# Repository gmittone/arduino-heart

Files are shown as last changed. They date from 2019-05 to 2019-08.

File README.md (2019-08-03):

# Arduino Heart

This project is born as gift to Giovanni and Beatrice marriage.

The aesthetical design is built around an heart with in front a color display with touch, two capacitive sensors on Giovanni and Beatrice names and the marriage date. On the back can be found an Arduino Due board as main controller, an esp8266 as wifi client (via SPI), an SD card, an RTC chip and a buzzer. All hardware information, with schematics and rendering, can be found on the `hardware` folder. Main source code can be found on `src` and `include`; `lib` contains all external libraries fetched with `git submodule`; `external` contains the esp8266 firmware used as wifi client over SPI.

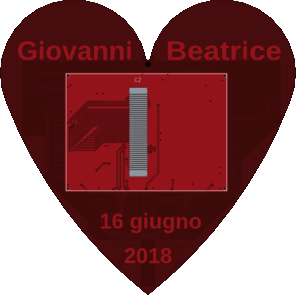
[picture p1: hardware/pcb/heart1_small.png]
Image of Yaktocat


# Features

- wifi client with WPA2 support
- rtc timer with alarm and clock
- ntp time syncronization
- sd card with FAT/FAT32
- color display and touch screen
- capacitive sensors
- jpeg/raw image rendering

# Build

Clone the main repository with the following command

```bash
git clone --recurse-submodules -j8  [repository]
```

then you can use _platformIO_, through emacs/terminal o Visual Studio Code, to build and upload the code to the arduino board through the usb programm port. Probably can be easy to write a cmake configuration file and avoid platformIO seen that the only external requirement is the Arduino framework for the _atmelsam_ platform.

Main configuration parameters live at `include/config.h` where you can find many _define_ to enable debugging to serial console and enable/disable functions.

# Todo

- use interrupt or timer to manage changes on display, like slideshow photo change or "marriage from" clean
- multiple udp/tcp socket like, ntp and webserver at the same time
- sleep mode with wake up
- memory usage optimization
- probably a clean up/unification on class management

# Thanks to

- Arduino/ESP8266 projects and all examples found on Internet
- Jiri Bilek for [WiFiSpi](https://github.com/JiriBilek/WiFiSpi) and [WiFiSpiESP](https://github.com/JiriBilek/WiFiSpiESP)
- Henning Karlsen for [UTFT](http://rinkydinkelectronics.com/library.php?id=51), [URTouch](http://rinkydinkelectronics.com/library.php?id=92) and [DS1307](http://rinkydinkelectronics.com/library.php?id=34)
- SAM scheduler [repository](https://github.com/arduino-libraries/Scheduler)
- Arduino SD library [site](http://www.arduino.cc/en/Reference/SD)
- Paul Stoffregen for [TimeAlarms](https://github.com/PaulStoffregen/TimeAlarms)
- Jack Christensen for [Timezone](https://github.com/JChristensen/Timezone)
- Bodmer for [JPEGDecoder](https://github.com/Bodmer/JPEGDecoder)
- Graham Lawrence for the [UTFT_SdRaw](https://github.com/ghlawrence2000/UTFT_SdRaw) code

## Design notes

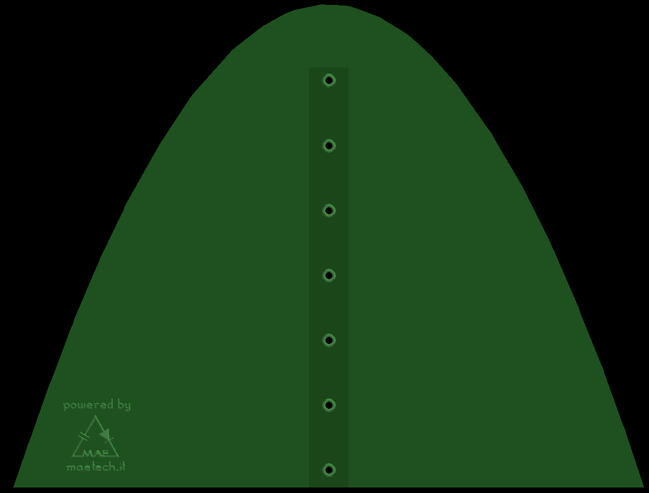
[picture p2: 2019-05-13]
hardware/pcb/stand2_2.png

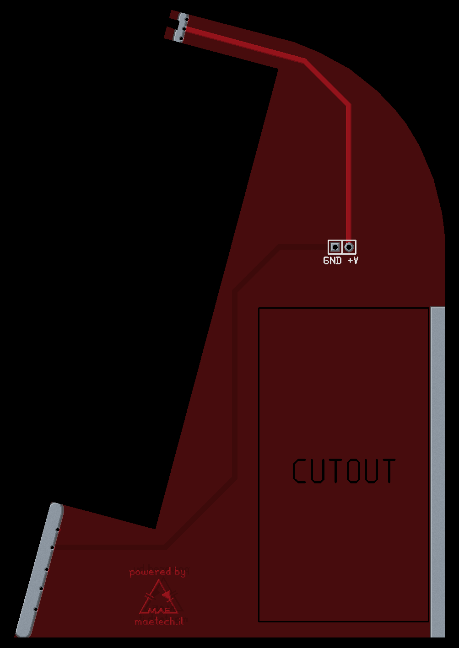
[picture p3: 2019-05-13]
hardware/pcb/stand1.png

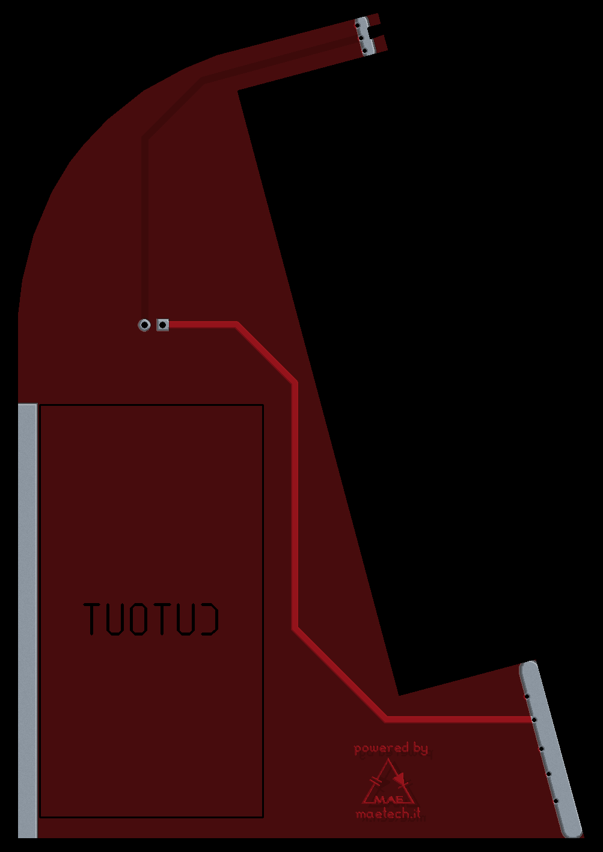
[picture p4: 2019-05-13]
hardware/pcb/stand2.png

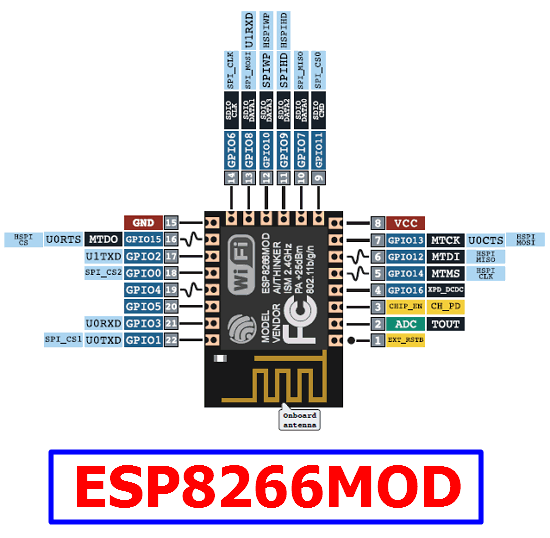
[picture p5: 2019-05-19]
hardware/pinout/ESP8266MOD-datasheet-pinout.gif

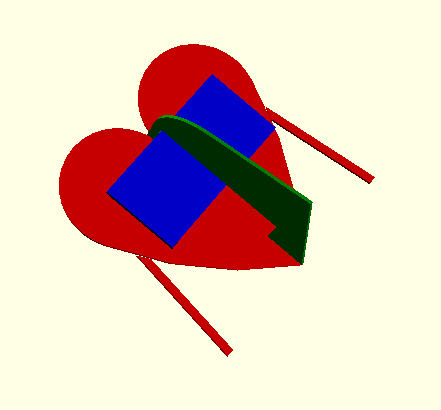
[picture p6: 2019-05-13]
hardware/3d/3d_1.png

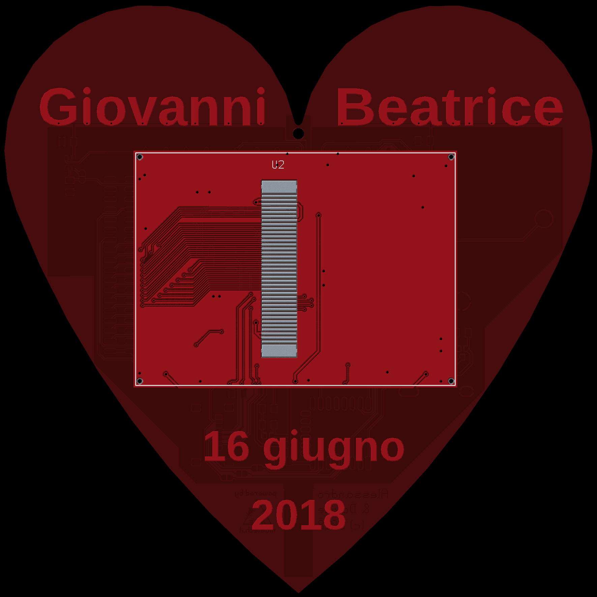
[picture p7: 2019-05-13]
hardware/pcb/heart1.png

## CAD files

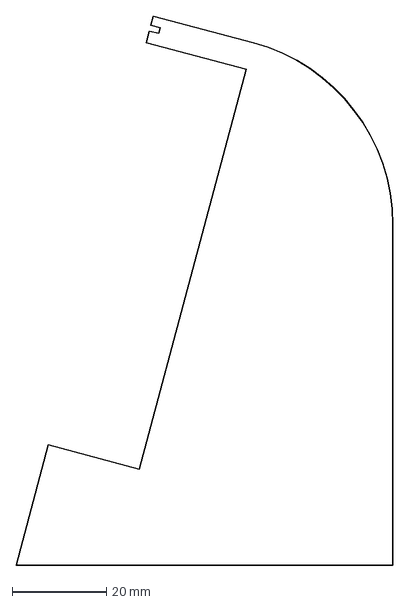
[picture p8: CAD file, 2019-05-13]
hardware/pcb/aux/stand.dxf
80.0 x 116.6 mm

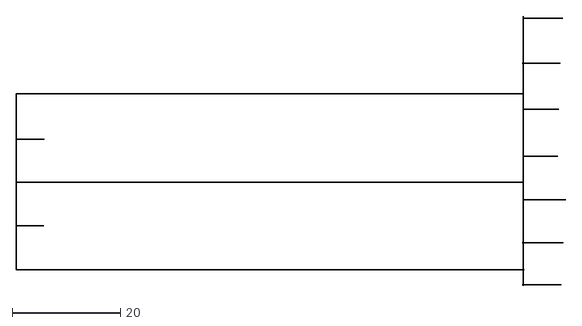
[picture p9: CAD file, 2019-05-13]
hardware/pcb/aux/rtc.dxf
101.4 x 49.8

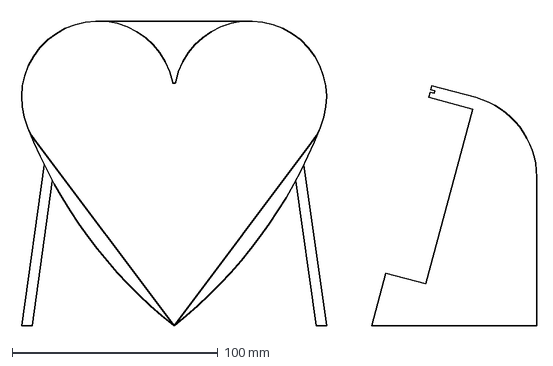
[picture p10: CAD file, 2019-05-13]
hardware/pcb/aux/heart.dxf
252.6 x 150.4 mm

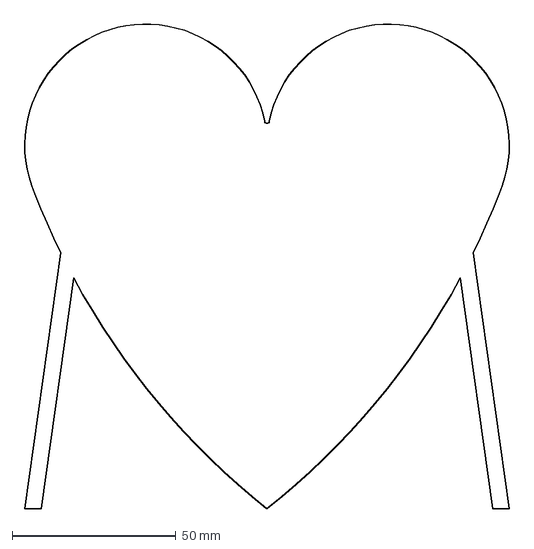
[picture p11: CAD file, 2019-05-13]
hardware/pcb/aux/heart_gambe.dxf
153.2 x 150.4 mm

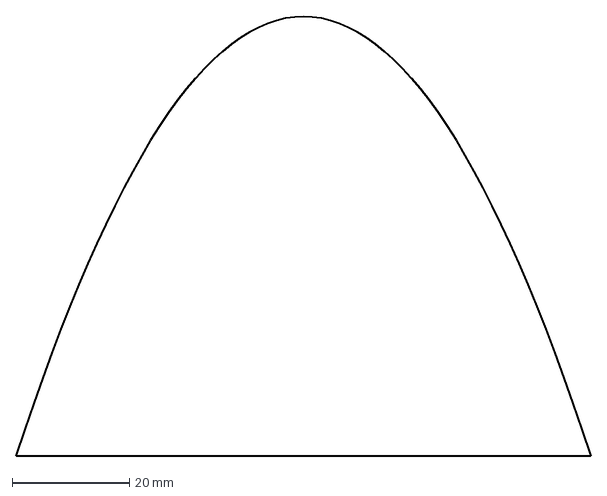
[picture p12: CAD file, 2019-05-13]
hardware/pcb/aux/stand2.dxf
98.0 x 75.0 mm

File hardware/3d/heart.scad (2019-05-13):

module arduino()
{
    color("blue")
    cube (size=[100,50,2]);
    color("black")
    translate([0,0,-10])
    {
        translate([3,0,0])
    cube (size=[5,50,10]);
        translate([10,3,0])
    cube (size=[70,2,10]);
        translate([10,46,0])
    cube (size=[70,2,10]);
    }
}

//cube (size=[150,150,2]);

module heart()
{
    color("red")
    linear_extrude(height = 2, center = false, convexity = 10)
    {
import (file = "pcb/aux/heart.dxf", layer = "0");
//import (file = "aux/heart.dxf", layer = "gambe");
    }
        
translate([25,65,12])
    arduino();

}

module stand()
{
    translate([-168,0,0])
    color("green")
    linear_extrude(height = 2, center = false, convexity = 10)
    {
import (file = "pcb/aux/heart.dxf", layer = "stand");
    }
    
    translate([80,0,-35])
    cube(size=[2,50,70]);
}

rotate([15,0,0]) heart();
translate([75,0,0]) rotate([0,-90,0]) stand();

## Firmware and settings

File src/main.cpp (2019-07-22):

/*
 * main.cpp - Probably nothing to say ;-)
 * Created by Davide `rainbow` Gerhard
 * 12 May 2019
 * For the license see LICENSE
 */

/* general configure header */
#include "config.h"

/* don't forget, we are using the arduino framework */
#include <Arduino.h>

/* Scheduler to manage multiple tasks */
#include <Scheduler.h>

/* include the capactivice touch sensors */
#include "cts.h"

/* include time management class */
#include "localTime.h"

/* include wifi management class */
#include "wifi.h"

/* include the ntp client class */
#include "ntpclient.h"

/* include web server class */
#include "webserver.h"

/* include display and touch class */
#include "display.h"

/* include file system */
#include "vfs.h"

/* include some useful functions */
#include "utility.h"

/* "thread" functions */
void cts_loop();
void display_loop();
void webserver_loop();
void esp8266serial_loop();
void localtime_loop();

/*
 * INITIALIZE the board
 */
void setup()
{
#if ENABLE_DISPLAY
  // Initialize the display
  display.init();
#endif

  // Initialize serial and wait for port to open:
  Serial.begin(ARDUINO_SERIAL_SPEED);

#if ENABLE_NETWORK && ENABLE_DEBUG
  Serial.println("Start listening on Serial1 for ESP8266 debug messages");
  // start listening on serial of ESP8266 for debug messages
  Scheduler.startLoop(esp8266serial_loop);
#endif

  // before everything configure the pads buttons;
  // they can be used as function trigger
  cts.init();

  // start clock
  localTime.init();

  // welcome screen on Serial
  serialWelcome();

#if ENABLE_SD
  // initialize vfs/sd card
  vfs.init();
#endif

#if ENABLE_DISPLAY
  // Welcome message
  display.drawWelcome();
#endif

#if ENABLE_NETWORK
  // initialize the wifi with config.h data
  wifi.init();

  // if the wifi is ready we can enable other network services
  if (wifi.isReady())
  {
    localTime.enableNTP();

#if ENABLE_WEB_SERVER
    // start web server
    webserver.init();
    Scheduler.startLoop(webserver_loop);
#endif
  }
#endif // ENABLE_NETWORK

  // start time loop
  Scheduler.startLoop(localtime_loop);

#if ENABLE_DISPLAY
  display.drawClock();
#endif

  // start the loop on pads
  Scheduler.startLoop(cts_loop);

#if ENABLE_DISPLAY
  // loop on display
  Scheduler.startLoop(display_loop);
#endif
}

/*
 * Keep alive the board ;-)
 */
void loop()
{
  delay(1000);
  yield();
}

/* "thread" loops */
void cts_loop()
{
  cts.loop();
  yield();
}
void display_loop()
{
  display.loop();
  yield();
}
void webserver_loop()
{
  webserver.loop();
  yield();
}

void esp8266serial_loop()
{
  wifi.readSerial();
  yield();
}

void localtime_loop()
{
  localTime.loop();
  yield();
}

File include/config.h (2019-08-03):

/*
 * config.h - Probably nothing to say ;-)
 * Created by Davide `rainbow` Gerhard
 * 12 May 2019
 * For the license see LICENSE
 */

#ifndef _CONFIG_H
#define _CONFIG_H

/* WiFi credentials */
#define WIFI_SSID "nuje_home"
#define WIFI_PASS "homepassword"

/* enable or disable debug messages
 * TODO:
 *   - move to macro INFO()/WARN()/ERR()
 */
#define ENABLE_DEBUG 0
#if ENABLE_DEBUG
#define DEBUG
#endif

/* enable ntp debug */
#define ENABLE_NTP_DEBUG 0

/* overwrite WiFiSpi configuration
 *
 * TODO:
 * seems it doesn't work rewriting _CONFIG_H_INCLUDED
 * of lib/WiFiSpi/src/utility/debug.h and
 * other definitions
 */
#define ENABLE_WIFI_DEBUG 0

/* enable or disable localTime debug messages
 */
#define ENABLE_TIME_DEBUG 0

/* enable or disable CTS debug messages
 */
#define ENABLE_CTS_DEBUG 0

/* enable or disable display debug messages
 */
#define ENABLE_DISPLAY_DEBUG 0

/* enable or disable the vfs debug messages */
#define ENABLE_VFS_DEBUG 0

/* enable or disable the network code */
#define ENABLE_NETWORK 1

/* enable SD card support */
#define ENABLE_SD 1

/* enable display */
#define ENABLE_DISPLAY 1

/* enable web server
 * TODO: manage multiple socket
 *       see https://github.com/JiriBilek/WiFiSpi/issues/14
 */
#define ENABLE_WEB_SERVER 0

/* 
 * define marriage time in unix timestamp
 * 06/16/2018 @ 11:00pm (UTC)
 */
#define MARIAGE_UNIXTIMESTAMP 1529146800

/* Arduino DUO serial output speed */
#define ARDUINO_SERIAL_SPEED 115200

/* ESP8266 serial port debuging */
#define ESP8266_SERIAL_SPEED 115200

/* define the ntp server used */
#define NTP_SERVER "pool.ntp.org"

/* define local time zone */
#define TIMEZONE "GMT"

/*
 * update interval of ntp
 * every 1h in ms
 */
#define NTP_UPDATE_INTERVAL 3600000

/*
 * folder on the sd that contains photos
 * on JPEG format (*.jpg) at size 480x320 pixels
 */
#define SD_PHOTOS_FOLDER "/PHOTOS"

/*
 * how many ms to wait on welcome screen
 * 
 * NOTE: with networking we could problably avoid it
 */
#define WELCOME_SCREEN_WAIT 2000

#endif

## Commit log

2019-05-13 add esp8266 firmware as submodule
    - we use WiFiSpiESP to use the esp8266 module as dummy bridge between
    arduino and wifi. In this way we can configure the ssid/wpa key from
    arduino code (or from GUI) and manage directly the tcp/udp/ssl
    sockets
    - imported as git submodule to manage upstream update
    https://github.com/JiriBilek/WiFiSpi
2019-05-13 basic wpa connection and ntp client
    - use WiFiSpi project to manage esp8266 as wifi bridge; this facility
    permit to manage all connections from the arduino code
    see more at https://github.com/JiriBilek/WiFiSpi
    - the WiFiSpi library is managed through platform to simplify
    centralized management; moved from git submodule
    - implement a simple ntp client as class; surely not compliant with
    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
2019-05-13 Rtc: library for on-board Ds1307 RTC chip
    - checkout to version 2.3.2
    Thanks Michael Miller
    Reference: https://github.com/Makuna/Rtc
2019-05-13 Scheduler: library to implement multiple loop tasks
    The Scheduler library enables the Arduino Due, Zero, and MKR1000 to
    run multiple functions at the same time. This allows tasks to happen
    without interrupting each other.
    Reference http://www.arduino.cc/en/Reference/Scheduler
2019-05-13 NTP client WIP
    - using Artuno NTPClient as base to have many facilities
    TODO:
    - strange connection error
    - sometime I see connection to 0.0.0.0:123
    [main.cpp, ntpclient.h, utility.cpp]
2019-05-13 hardware: add Arduino DUE and ESP8266MOD pinout
2019-05-13 updated hardware folder
    [heart.dxf, heart.scad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]
2019-05-13 cts: implement class to manage capacitive pads
2019-05-13 SD: library to manage the sd card with FAT16/FAT32
    Reference: https://www.arduino.cc/en/Reference/SD
2019-05-13 wifi class to manage the wifi connection
    - the board starts without wifi board
    - changing #define macro to disable/enable wifi debug doesn't work as
    expected; see config.h for details
    Other changes:
    - enable/disable display code at compile time
    - cts: use ready boolean value with prefix; we use the class
    - move copyright to 2018/2019
    [config.h, display.cpp, main.cpp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]
2019-05-13 cts: implement simple filter on touch
    - probably needs more adjustment if we implement game or something
    that need high speed button
2019-05-13 move on with display
    - built a welcome screen with heart and "created by"
    - images used on display must be put on include/display after
    converted with
    http://rinkydinkelectronics.com/t_imageconverter565.php
    - main screen with clock, button and calendar; needs new RTC
    - library (next commit)
    - move serial speed from 9600 to 115200 to reduce the boot
    delay (serial welcome saturate buffer so freeze other tasks).
    tryed to change the buffer size but doesn't work as expected, also
    because Arduino library doesn't use #ifdef
    - fixed scheduler behaviour; move all main loops to main.ccp and call
    Class::loop() on each task.
    [config.h, cts.cpp, display.cpp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]
2019-05-13 DS1307: import library version 2.0 (I²C Real-Time Clock)
    The DS1307 serial real-time clock (RTC) is a low-power, full
    binary-coded decimal (BCD) clock/calendar plus 56 bytes of NV
    SRAM. Address and data are transferred serially through an I²C,
    bidirectional bus. The clock/calendar provides seconds, minutes,
    hours, day, date, month, and year information.
    - version 2.0 - 13 Feb 2016
    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
2019-05-13 move from Rtc to DS1307 library; basic interface working
    - move from Rtc to DS1307 library; though I see that many functions
    was present into Rtc; as always, after the move :(
    - rework of main.cpp to use the new library without custom interface
    in the middle, heart_rtc class.
    - fixes some glitches on the clock interface and added "Married from"
    with seconds in the middle of the analog clock.
    - seconds pass quite slow and the clock change very slowly; this
    behaviour was already seen with the old library and
    print(). Nothing change if I put the display.loop() on the main
    loop() and disable all other Schedule()s.
    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
    [config.h, cts.cpp, display.cpp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]
2019-05-19 esp8266: enable digital pin 16 on arduino to enable the board
2019-07-22 big changes: display working + basic photo slideshow
    sorry for the big commit but I worked on too many things at the same
    time that I lost separation ;-(
    Now the photos slideshow can draw jpeg (with an old school effect) and
    raw images converted with
    WHAT DOESN'T WORK
    - photo: the image squares are rotated
    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
    [config.h, cts.cpp, display.cpp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]
2019-08-03 Timezone: new library
    Arduino library to facilitate time zone conversions and automatic
    daylight saving (summer) time adjustments.
2019-08-03 fix jpeg photos display on landscape and implement timezone
    - implemented timezone with fixed (:) zone CEST/CET
    - fixed jpeg rendering on landscape
    [config.h, display.cpp, image_jpeg.cpp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]
